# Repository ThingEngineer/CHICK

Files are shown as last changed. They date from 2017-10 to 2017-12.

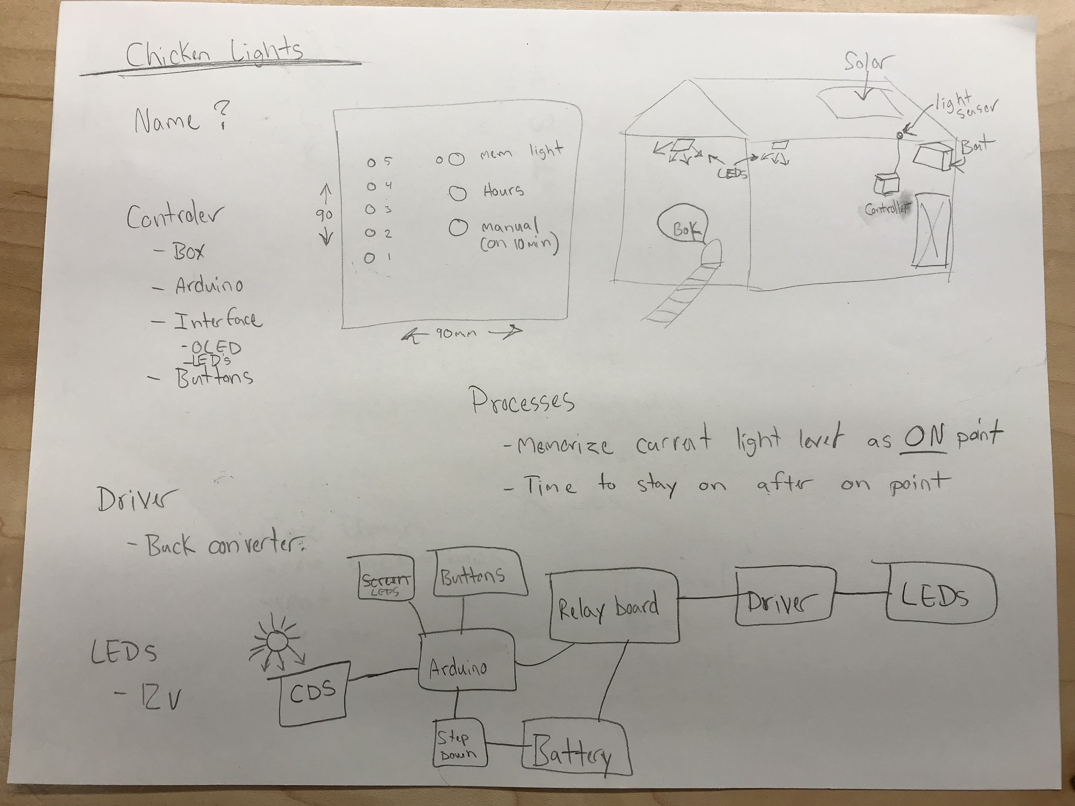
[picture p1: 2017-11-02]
doc/images/idea_sketch.jpg

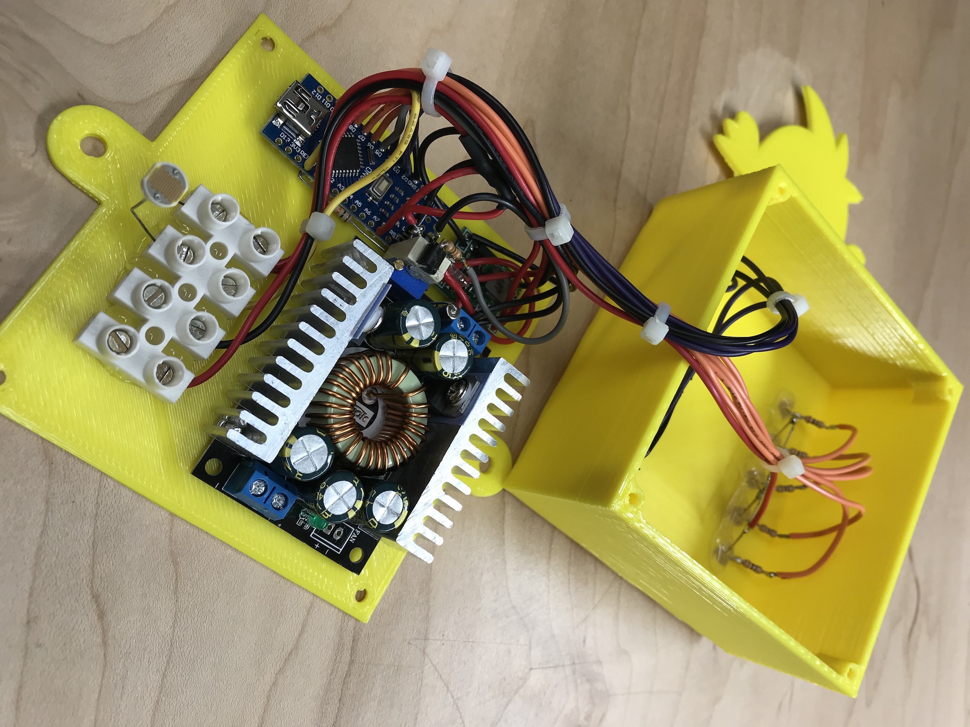
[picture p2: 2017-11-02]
doc/images/inside_assymbled_01a.jpg

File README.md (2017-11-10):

This repository contains 3D hardware designs, firmware and other documentation for CHICK.

## Project Description
CHICK [Chicken House Illumination Control boKs] is an open source, simple to use, minimalistic approach daylight automated 12 volt powered LED light controller. Its purpose is to extend daylight hours in a chicken house/coup thus promoting greater egg production.
You can read more info about that here: https://poultrykeeper.com/general-chickens/light-for-layers/

Some years ago I installed a solar panel, charge controller, battery bank and LED lighting with timer and manual functions in my mothers chicken coup. The timer was an off the shelf product that I modified to work with low voltage. It worked fairly reliably but the time on and off had to be adjusted with the seasons quite often. I wanted a simple controller without the need to set timers, adjusted time for DST, and change time with the seasons. And did I say I wanted it to be SIMPLE?!



Thingiverse files for CHICK: https://www.thingiverse.com/thing:2595492

## Operation
Operating CHICK goes like this. There is a manual button, push on/push off. You can turn the lights on or off without affecting the current on/off cycle. To set the on time (or light level at which it triggers the lights to turn on) you simply do this: At the time of day when the light level reaches the point where you want the lights to come on, say at dusk you simply hold down the set button and wait for the LEDs to flash. The code takes multiple samples over 3 seconds to verify a good reading then saves that level to EEPROM. Now you just press the hours button until the LED corresponding to the number of hours you want the lights to remain on is lit (1-5). This is also saved to EEPROM. Your done, when the sun goes down and the light reaches the level at which you specified the code begins a 5 minute verification checking the level once each minute to ensure the level is still below the trigger level. Once that condition is met the lights are turned on and remain on for the time set in hours. Once the time is up the lights shut off and are now waiting for a light cycle (dawn) above the trigger level to reset at which point the code again is waiting for dusk. If the lights are triggered by a temporary dark event such as clouds, solar eclipse, a bird sitting on the sensor, etc. an increase in light level above the saved trigger point will result in the count down timer to shut the lights off being sped up significantly.

The code is well documented and any questions about it's operation should be able to be gleaned from there, if not feel free to open an issue or send me a message directly.

## Open Source
  <br />This work is licensed under a <a rel="license" href="http://creativecommons.org/licenses/by-sa/4.0/">Creative Commons Attribution-ShareAlike 4.0 International License</a>.

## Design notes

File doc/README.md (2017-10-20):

## Attributions, References and Sources
1. Chick SGV - https://commons.wikimedia.org/wiki/File:Emojione_1F425.svg
2. Gikfun USB Nano V3.0 ATmega328 CH340G 5V 16M Micro-controller board For Arduino - https://www.amazon.com/Gikfun-ATmega328-Micro-controller-Arduino-EK1620x3/dp/B00SGMEH7G
3. Adafruit has a great page all about using Photocells - https://learn.adafruit.com/photocells/using-a-photocell

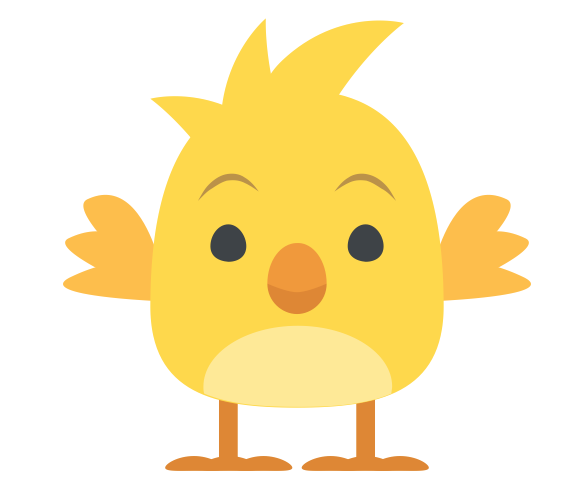
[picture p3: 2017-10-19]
doc/images/Emojione_1F425.png

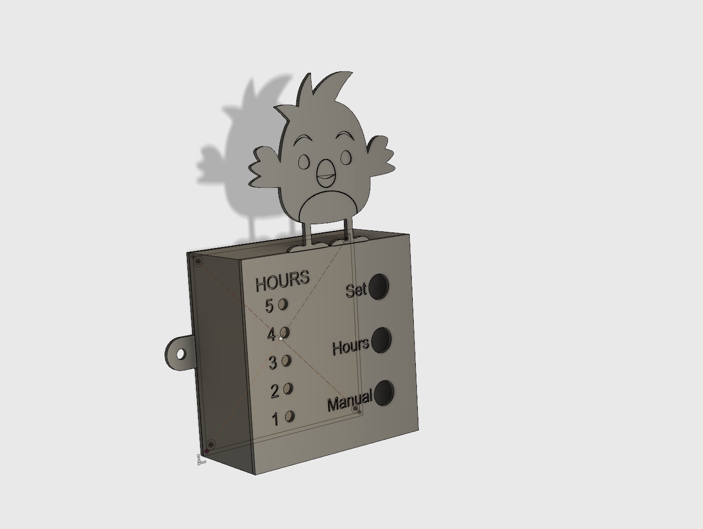
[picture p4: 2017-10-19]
doc/images/3d_render.jpg

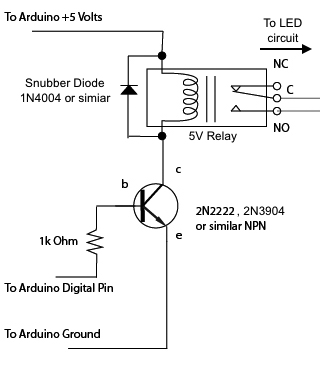
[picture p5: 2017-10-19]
doc/images/arduino_relay.jpg

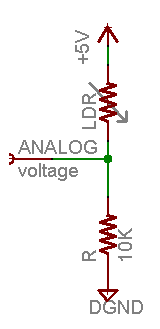
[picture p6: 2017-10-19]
doc/images/light_cdsliteschem.gif

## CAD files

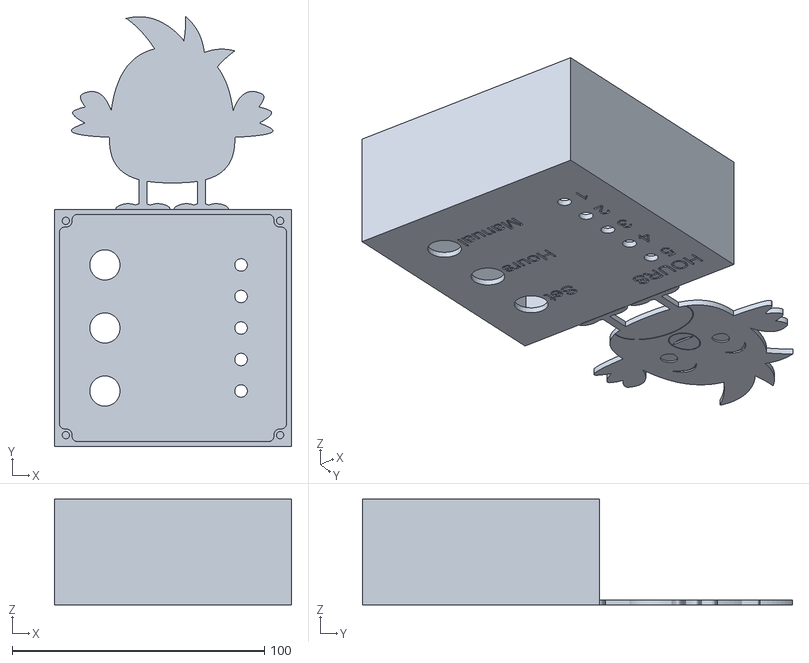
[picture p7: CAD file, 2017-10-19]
hardware/CHICK Case.stl
94.0 x 170.5 x 42.0

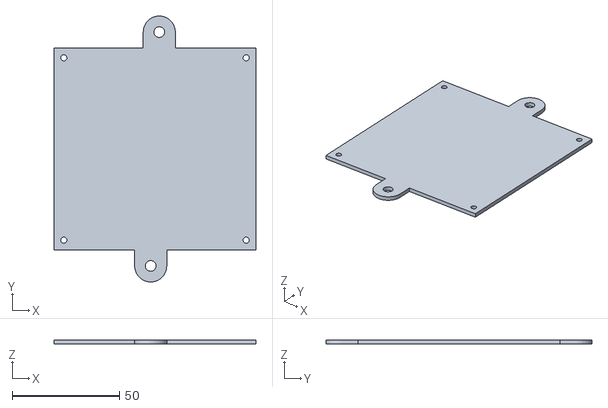
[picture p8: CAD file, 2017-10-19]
hardware/CHICK Lid.stl
94.0 x 124.0 x 2.00

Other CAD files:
hardware/CHICK Case.f3d

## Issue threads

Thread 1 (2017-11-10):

Implement a watchdog timer

ThingEngineer, 2017-11-10:
I have not had a problem with lockups since installing the device. This is preventive and to follow best practice.

ThingEngineer, 2017-11-10:
Resolved by commit fbf60617e18a266c9169bcb203b2138b0310bbd8

Closed 2017-11-10.

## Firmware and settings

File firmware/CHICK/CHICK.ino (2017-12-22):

/*
  CHICK - Chicken House Illumination Control boKs

  CHICK is an open source, simple to use, minimalistic approach 
  daylight automated 12 volt powered LED light controller. 
  Its purpose is to extend daylight hours in a chicken house/coup, 
  thus promoting greater egg production. 
  You can read more info about that here: 
  https://poultrykeeper.com/general-chickens/light-for-layers/

  GitHub Project: https://github.com/ThingEngineer/CHICK
  Thingiverse files for CHICK: https://www.thingiverse.com/thing:2595492

  Functions:
  - Memorize current light level as the trigger on point.
  - Remain on for 1-5 hours.
  - With manual On/Off

 The circuit:
  * 3 buttons connected from ground to digital pins X-X control 
    memorization of light level, BREAK OUT EACH BUTTON
  * 5 LEDs connected from +5V to digital pins 6-10 indicate 
    the number of hours the main lighting LEDs will remain on
    after they are triggered on by the CDS sensor level event
  * CDS Photocell
  * Relay > DC-DC Buck Converter

 Created 18 October 2017
 Modified 10 November 2017
 By Josh Campbell

 v1.0 - 11/02/2017

 This work is licensed under a Creative Commons Attribution-ShareAlike 4.0 International License.
 */

#include <EEPROM.h>       // library to access the EEPROM read write functions
#include <avr/wdt.h>      // library to access watchdog functions

// pin the Relay is connected to
const int relayPin = 5;   // LED control relay

// pins the LEDs are connected to
const int led1Pin = 6;    // Hour 1
const int led2Pin = 7;    // Hour 2
const int led3Pin = 8;    // Hour 3
const int led4Pin = 9;    // Hour 4
const int led5Pin = 10;   // Hour 5

// pins the buttons are connected to
const int setButtonPin = 2;        // Set button
const int hoursButtonPin = 3;      // Hours button
const int manualButtonPin = 4;     // Manual button

const int cdsPin = 0;           // CDS light sensor

int manualButtonState = 0;      // variable for reading the manual button status
int hoursButtonState = 0;       // variable for reading the hours button status
int setButtonState = 0;         // variable for reading the set button status
int initialLightReading = 0;    // the initial value read from the CDS/Photocell sensor
int lightReading = 0;           // value read from the CDS/Photocell sensor
const int lightDeltaMax = 10;   // maximum deviation from initial and current light level readings
const int triggerLevelAddr = 0; // address where the saved trigger light level is saved in EEPROM
int triggerLevel = 0;           // level at which the LEDs are triggered ON
byte triggerCounter = 0;        // number of valid light level triggers (current reading is less than or equal to triggerLevel)
const byte triggerCount = 5;    // number of valid light level triggers required to activate LEDs
byte shutOffDelayCounter = 0;   // count down timer to shut LEDs off
bool LEDstate = false;          // flag to indicate LED state (true = ON, false = OFF)
bool nightFlag = false;         // flag set at night that must be reset at dawn before LEDs can be retriggered

int currentButtonPressed = 0;   // the current button pressed
int lastButtonPressed = 0;      // the last button pressed
int buttonCheck = 0;            // button press checksum
bool buttonValid = false;       // valid button press flag

unsigned long lastDebounceTime = 0;   // the last time the output pin was toggled
unsigned long debounceDelay = 150;    // the debounce time delay

long lastTime = 0;              // last saved millisecond count
byte minutesCounter = 0;        // minutes counter
byte hoursCounter = 0;          // hours counter
bool minuteFlag = false;        // minute flag - triggered once each minute
bool hourFlag = false;          // hour flag - triggered once each hour

const byte shutOffDelayAddr = 2;// address where the saved shut off delay is saved in EEPROM
byte shutOffDelay = 0;          // number of hours that the LED will remain on before being shut off

void setup() {

  // load light trigger level from EEPROM
  triggerLevel = EEPROMReadInt(triggerLevelAddr);
  
  // load shut off delay from EEPROM
  shutOffDelay = EEPROMReadInt(shutOffDelayAddr);

  // Set pin modes
  pinMode(manualButtonPin, INPUT_PULLUP);
  pinMode(hoursButtonPin, INPUT_PULLUP);
  pinMode(setButtonPin, INPUT_PULLUP);
  pinMode(led1Pin, OUTPUT);
  pinMode(led2Pin, OUTPUT);
  pinMode(led3Pin, OUTPUT);
  pinMode(led4Pin, OUTPUT);
  pinMode(led5Pin, OUTPUT);
  pinMode(relayPin, OUTPUT);

  // Ensure LEDs are off (active LOW)
  digitalWrite(led1Pin, HIGH);
  digitalWrite(led2Pin, HIGH);
  digitalWrite(led3Pin, HIGH);
  digitalWrite(led4Pin, HIGH);
  digitalWrite(led5Pin, HIGH);
  // Ensure relay is off (active HIGH)
  digitalWrite(relayPin, LOW);

  // Emable watchdog timer with 8 second timeout
  wdt_enable(WDTO_8S);
}

void loop() {
  wdt_reset();    // reset the watchdog timer

  // Read current button states
  manualButtonState = digitalRead(manualButtonPin);
  hoursButtonState = digitalRead(hoursButtonPin);
  setButtonState = digitalRead(setButtonPin);

  // ****************************************************
  // Button debouncing and validation
  buttonCheck = manualButtonState + hoursButtonState + setButtonState;  // allows ignoring pressing multiple buttons at once
  
  if (manualButtonState == LOW) currentButtonPressed = 1;
  if (hoursButtonState == LOW) currentButtonPressed = 2;
  if (setButtonState == LOW) currentButtonPressed = 3;

  // if a button was previously validated
  if (buttonValid == true)
  {
    lastButtonPressed = 0;      //erase button states to prevent button code from running again
    currentButtonPressed = 0;
  }

  // if only one button is pressed, no button was previously pressed and no button is currently valid
  if (buttonCheck == 2 && lastButtonPressed == 0 && buttonValid == false)
  {
    lastButtonPressed = currentButtonPressed;   // save current button pressed
    lastDebounceTime = millis();                // save current time
  }
  // if no button is currently valid, only one button is pressed, the last button pressed is the current button pressed and we are over the minimum debouse time delay
  else if (buttonValid == false && buttonCheck == 2 && lastButtonPressed == currentButtonPressed && ((millis() - lastDebounceTime) > debounceDelay))
  {
    buttonValid = true;
  }
  // if a debounce has occured AND, a single (one) button is not pressed OR last and current buttons do not match
  else if (lastDebounceTime !=0 && buttonCheck != 2 || lastButtonPressed != currentButtonPressed)
  {
    lastDebounceTime = 0;       // clear debouce timer
    currentButtonPressed = 0;   // clear current button pressed
    lastButtonPressed = 0;      // clear last button pressed
    buttonValid = false;        // clear button validation flag

    refreshLEDs();              // clear LEDs and turn the corresponding LED to indicate hours remaning in the countdown timer
  }
  // END Button debouncing and validation
  // ****************************************************

  // ****************************************************
  // Manual Button Press
  if (buttonValid == true && currentButtonPressed == 1)
  {
    digitalWrite(relayPin, digitalRead(relayPin) ^ 1);    // toggle the relay pin (does not interfere with timer on/off state)
  }
  // END Manual Button Press
  // ****************************************************

  // ****************************************************
  // Hours Button Press
  if (buttonValid == true && currentButtonPressed == 2)
  {
    shutOffDelay++;
    if (shutOffDelay >= 6) shutOffDelay = 1;
    
    if (shutOffDelay == 1) digitalWrite(led1Pin, LOW);      // LED indication of shutOffDelay selection in hours
    if (shutOffDelay == 2) digitalWrite(led2Pin, LOW);
    if (shutOffDelay == 3) digitalWrite(led3Pin, LOW);
    if (shutOffDelay == 4) digitalWrite(led4Pin, LOW);
    if (shutOffDelay == 5) digitalWrite(led5Pin, LOW);
    delay(50);  // short delay for inidcator LED
    
    // save this value as the new shut off delay
    EEPROMWriteInt(shutOffDelayAddr, shutOffDelay);
  }
  // END Hours Button Press
  // ****************************************************

  // ****************************************************
  // Set Button Press
  if (buttonValid == true && currentButtonPressed == 3)
  {
    saveLightLevel();
  }
  // END Set Button Press
  // ****************************************************

  if(millis()-lastTime > 60000)  // if 60 seconds have elasped
  {
    minutesCounter++;     // increment minutes counter
    minuteFlag = true;    // set minute flag
    lastTime = millis();  // save current millisecond as lastTime
  }
  
  if(minutesCounter > 60)  // if 60 minutes have elapsed
  {
    hoursCounter++;       // increment hours counter
    hourFlag = true;      // set hour flag
    minutesCounter = 0;   // reset minutes counter
  }

  // Code run on the minute
  if (minuteFlag == true)
  {
    if (LEDstate == false)                  // only run this code if the LEDstate is false
    {
      lightReading = analogRead(cdsPin);    // read the analog in value of the CDS sensor

      if (lightReading < triggerLevel && nightFlag == false)      // if current reading is less than or equal to triggerLevel and it is no longer nightime
      {
        triggerCounter++;                   // increment triggerCounter
        if (triggerCounter == 1) digitalWrite(led1Pin, LOW);      // LED indication of trigger counter stage
        if (triggerCounter == 2) digitalWrite(led2Pin, LOW);
        if (triggerCounter == 3) digitalWrite(led3Pin, LOW);
        if (triggerCounter == 4) digitalWrite(led4Pin, LOW);
      }
      else if (lightReading > triggerLevel &&  nightFlag == false)
      {
        triggerCounter = 0;                 // or reset triggerCounter
        refreshLEDs();
      }

      if (triggerCounter == triggerCount && nightFlag == false)   // if triggerCounter hits the threshold at it is not nightime activate LEDs and countdown timer
      {
        digitalWrite(relayPin, HIGH);       // turn LED relay on
        nightFlag = true;                   // set nighttime flag
        LEDstate = true;                    // indicate LED relay is on
        shutOffDelayCounter = shutOffDelay; // load shutOffDelay to the shutOffDelayCounter
        refreshLEDs();                      // turn the corresponding LED to indicate hours remaning in the countdown timer
        minutesCounter = 0;                 // reset minutes
        hoursCounter = 0;                   //   and hours to ensure a fresh counter start
        hourFlag = false;                   // clear just incase an hour was triggered this minute
      }

      if (lightReading > triggerLevel && nightFlag == true)
      {
        if (triggerCounter == 0)            // LED indication of trigger counter stage
        {
          digitalWrite(led1Pin, LOW);
          digitalWrite(led2Pin, LOW);
          digitalWrite(led3Pin, LOW);
          digitalWrite(led4Pin, LOW);
        }
        triggerCounter++;                   // increment triggerCounter
        if (triggerCounter == 2) digitalWrite(led4Pin, HIGH);     // LED indication of trigger counter stage
        if (triggerCounter == 3) digitalWrite(led3Pin, HIGH);
        if (triggerCounter == 4) digitalWrite(led2Pin, HIGH);
        if (triggerCounter == 5) digitalWrite(led1Pin, HIGH);
      }
      else if (lightReading < triggerLevel && nightFlag == true)
      {
        triggerCounter = 0;                 // or reset triggerCounter
        refreshLEDs();
      }

      if (triggerCounter == triggerCount && nightFlag == true)   // if triggerCounter hits the threshold and it is nightime
      {
        nightFlag = false;                  // reset nighttime flag
      }
      
    }
    minuteFlag = false;                     // reset minute flag
  }

  // Code run on the hour
  if (hourFlag == true)
  {
    if (LEDstate == true)                   // only run this code if the LEDstate is true
    {
      shutOffDelayCounter--;                // decrement the shutOffDelayCounter
      if (shutOffDelayCounter == 0)
      {
        digitalWrite(relayPin, LOW);        // turn LED relay off
        LEDstate = false;                   // indicate LED relay is off
      }
      refreshLEDs();                        // turn the corresponding LED to indicate hours remaning in the countdown timer

      lightReading = analogRead(cdsPin);    // read the analog in value of the CDS sensor
      // if we think it is night time but the light level is above the trigger level then speed up the timer to shut the light off sooner
      // the first hour will be normal but each hour afer that will only be two minutes
      if (nightFlag == true && lightReading > triggerLevel) minutesCounter = 58;
    }

    hourFlag = false;  // reset hour flag
  }

}

void saveLightLevel()
{
  // sample light level over time and show LEDs to indicate progress
  sampleLight:
  wdt_reset();    // reset the watchdog timer
  initialLightReading = analogRead(cdsPin);
  delay(500);
  digitalWrite(led1Pin, LOW);
  lightReading = analogRead(cdsPin);
  if ( levelDeltaCheck(initialLightReading, lightReading) ) goto restart;
  delay(500);
  if (digitalRead(setButtonPin)) return;
  digitalWrite(led2Pin, LOW);
  lightReading = analogRead(cdsPin);
  if ( levelDeltaCheck(initialLightReading, lightReading) ) goto restart;
  delay(500);
  if (digitalRead(setButtonPin)) return;
  digitalWrite(led3Pin, LOW);
  lightReading = analogRead(cdsPin);
  if ( levelDeltaCheck(initialLightReading, lightReading) ) goto restart;
  delay(500);
  if (digitalRead(setButtonPin)) return;
  digitalWrite(led4Pin, LOW);
  lightReading = analogRead(cdsPin);
  if ( levelDeltaCheck(initialLightReading, lightReading) ) goto restart;
  delay(500);
  if (digitalRead(setButtonPin)) return;
  digitalWrite(led5Pin, LOW);
  lightReading = analogRead(cdsPin);
  if ( levelDeltaCheck(initialLightReading, lightReading) ) goto restart;
  delay(500);
  lightReading = analogRead(cdsPin);
  if ( levelDeltaCheck(initialLightReading, lightReading) ) goto restart;
  triggerLevel = lightReading;

  // save this value as the ON triger level
  EEPROMWriteInt(triggerLevelAddr, triggerLevel);
  
  // flash LEDs to indicate the new trigger level was saved
  digitalWrite(relayPin, HIGH); // relay on
  digitalWrite(led1Pin, HIGH);
  digitalWrite(led2Pin, HIGH);
  digitalWrite(led3Pin, HIGH);
  digitalWrite(led4Pin, HIGH);
  digitalWrite(led5Pin, HIGH);
  delay(300);
  digitalWrite(relayPin, LOW); // relay off
  digitalWrite(led1Pin, LOW);
  digitalWrite(led2Pin, LOW);
  digitalWrite(led3Pin, LOW);
  digitalWrite(led4Pin, LOW);
  digitalWrite(led5Pin, LOW);
  delay(300);
  return;

  // Max delta range error, clear LEDs and restart sampling
  restart:
  delay(25);   // small delay before clearing to help indicate what is happening
  digitalWrite(led1Pin, HIGH);
  digitalWrite(led2Pin, HIGH);
  digitalWrite(led3Pin, HIGH);
  digitalWrite(led4Pin, HIGH);
  digitalWrite(led5Pin, HIGH);
  goto sampleLight;
}

// This function first clears the LEDs turns on the corresponding LED to indicate hours remaning in the countdown timer
void refreshLEDs()
{
  // clear LEDs
  digitalWrite(led1Pin, HIGH);
  digitalWrite(led2Pin, HIGH);
  digitalWrite(led3Pin, HIGH);
  digitalWrite(led4Pin, HIGH);
  digitalWrite(led5Pin, HIGH);

  if (LEDstate == true)    // turn on hour indicator LED only if LEDstate is true (on)
  {
    if (shutOffDelayCounter == 5) digitalWrite(led5Pin, LOW);  // turn on LED #5
    if (shutOffDelayCounter == 4) digitalWrite(led4Pin, LOW);  // turn on LED #4
    if (shutOffDelayCounter == 3) digitalWrite(led3Pin, LOW);  // turn on LED #3
    if (shutOffDelayCounter == 2) digitalWrite(led2Pin, LOW);  // turn on LED #2
    if (shutOffDelayCounter == 1) digitalWrite(led1Pin, LOW);  // turn on LED #1
  }
  
  return;
}

bool levelDeltaCheck(int p_initialLightReading, int p_lightReading)
{
  if ( (initialLightReading - lightDeltaMax > lightReading) || (initialLightReading + lightDeltaMax < lightReading) ) return true;
  return false;
}

// this function will write a 2 byte integer to the eeprom at the specified address and address + 1
void EEPROMWriteInt(int p_address, int p_value)
{
  byte lowByte = ((p_value >> 0) & 0xFF);
  byte highByte = ((p_value >> 8) & 0xFF);

  EEPROM.write(p_address, lowByte);
  EEPROM.write(p_address + 1, highByte);
}

// this function will read a 2 byte integer from the eeprom at the specified address and address + 1
unsigned int EEPROMReadInt(int p_address)
{
  byte lowByte = EEPROM.read(p_address);
  byte highByte = EEPROM.read(p_address + 1);

  return ((lowByte << 0) & 0xFF) + ((highByte << 8) & 0xFF00);
}

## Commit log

2017-10-19 Initial Commit
    Added project folders, test firmware, images, datasheets and CAD files.
    [CHICK Case.f3d, CHICK Case.stl, CHICK Lid.stl]
2017-10-21 Mapped LEDs and Buttons
2017-10-21 Basic CDS functionality and doc update
    Basic light level trigger of LED relay. Update header documentation.
2017-10-21 Button/LED check
    Basic button and LED test, all good!
2017-10-26 Set initial states
    Ensure initial states are correct
    [CHICK.ino]
2017-10-26 Correct button pin assignments
    Pins were flip-flopped
    [CHICK.ino]
2017-10-26 Button debouce & validation functionality added
2017-10-28 update triggerLevel variable and flash relay on save
2017-10-29 Slight user feed back adjustment
    Added a small delay before clearing LEDs in the saveLightLevel function
    to help indicate what is happening
2017-10-30 Manual button function
    Added a manual on/off function that will not affect the current state
    of the timer on/off.
2017-10-30 Comment out cds test code
    Preparation for writing the timer1 ISR
2017-10-30 Timer 1 ISR
    1Hz ISR setup and test code (blink LED1)
2017-10-31 missing type
    shutOffDelayAddr was missing type (byte)
    [CHICK.ino]
2017-10-31 Seconds, minutes, hours counter
    Create seconds, minutes and hours counter with flags for minutes and
    hours in the timer1 ISR.
2017-10-31 Replace ISR with millis counter
    Simpler and smaller code, better suited for this purpose
    [CHICK.ino]
2017-11-01 Cleaned up and timer routines
2017-11-01 Replace old code with refreshLED routine
    [CHICK.ino]
2017-11-02 Minute code tweak
    Made else if statements better defined, and comment typo fix.
    [CHICK.ino]
2017-11-02 False night trigger fix
    Added code to speed up the timer if a false night (low light level) was
    detected such as a cloud, solar eclipse, or bird standing on the
    sensor, etc… This will shut the LEDs of faster. If the light level
    drops below the trigger level again the timer will slow back down.
    [CHICK.ino]
2017-11-02 Changed timer variables from fast test values to normal
2017-11-02 Comment night time timer speed increase
2017-11-02 Rotate assembled pic
2017-11-02 Resized assembled pic
2017-11-10 Added basic watchdog timer functionality
